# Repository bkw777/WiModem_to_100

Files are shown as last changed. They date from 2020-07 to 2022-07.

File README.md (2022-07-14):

# WiModem232 to "Model T" portable computers

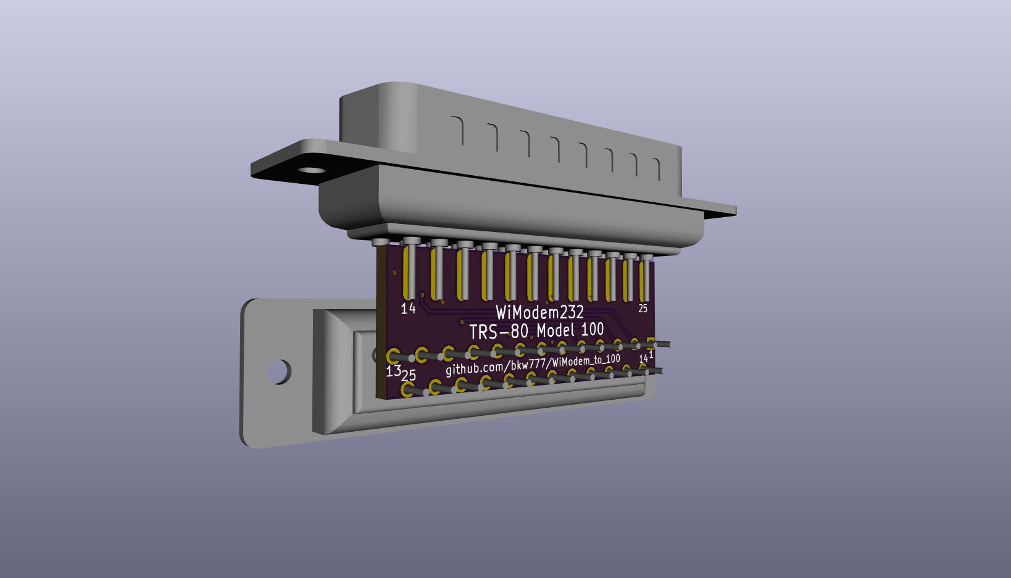
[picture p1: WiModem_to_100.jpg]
  
More pictures: <https://photos.app.goo.gl/hjoC3vnfZxWbFPRW6>



[BOM from DigiKey](https://www.digikey.com/short/z9nm2v)

RS-232 male-male gender-changer for connecting a [WiModem232](https://www.cbmstuff.com/proddetail.php?prod=WiModem232OLED) to a TRS-80 Model 100, or any of the similar machines which has a female DB25 RS-232 DTE connector.

It does 3 things:
- Gender-changer. Both the WiModem232 and Model 100 and clones have female connectors. So a gender-changer or male-male cable is needed to connect them.
- Faces the WiModem232's status led and oled display towards the user. A standard mini gender-changer flips the WiModem232 over so it faces down.
- Holds the Wimodem232 vertical instead of horizontal. This just takes up less desk space and makes it less likely to knock the WiModem232 off of the serial port, and makes it a little easier to read the display from a normal position.

Wired straight-through, not null-modem. The WiModem232, like any other modem or peripheral, is wired as a DCE device, and the Model 100, like any other computer or host, is wired as a DTE device, and so to connect the two, you use a straight-through connection. The RS-232 pins; 1-8, 20, & 22, are connected 1:1 from one connector to the other.  
Pin 1 is also the ground plane / copper pour on both sides of the board.

# Compatibility  
This is for attaching the WiModem232 to any of these machines  
- TRS-80/Tandy Model 100, 200, & 600  
- NEC PC-8201, PC-8201a, & PC-8300  
- Kyocera/Kyotronic KC-85

But notably, NOT these  
- Tandy Model 102  
- Olivetti M10

On Tandy 102 & Olivetti M10 machines, the DB25 connector is upside down, and so this adapter would point the WiModem232 down into the table.

For Tandy 102 & Olivetti M10, you can use an ordinary [25-pin mini gender-changer](https://duckduckgo.com/?q=db25+mini+gender+changer+male), and the WiModem232 will point straight out from the back of the machine instead of standing vertical, and with the LED and OLED screen facing up.

This PCB is designed to use [db25 connectors with through-hole legs](https://www.digikey.com/short/z9nm2v), not solder cups.  

<!--
# Power from BCR port  
<img src="https://github.com/bkw777/BCR_Breakout/blob/master/BCR_USB_PWR.jpg" width=300>  
You can power the WiModem232 from the computer with this <a href="https://github.com/bkw777/BCR_Breakout">BCR-USB power adapter</a> and a usb cable.  

(Not Kyotronic KC-85 or TANDY 600, they do not have a BCR port)

## USB Cables
|Computer Model|Computer End|WiModem232 End|Length|USB Cables|
|---|---|---|---|---|
| TRS-80&nbsp;Model&nbsp;100 | ![](USB_A_100_200.png)<br>![](USB_A_NEC.png) | ![](USB_Mini_ALL.png) | 20cm | <https://amazon.com/dp/B00NIGPK62/><hr><https://www.aliexpress.com/item/32313051153.html><hr><https://www.usbfirewire.com/parts/rr-2mbr01-12gl.html#RR-2MBR01-06GL> |
| TANDY&nbsp;102 | ![](USB_A_102_M10.png)<br>![](USB_A_100_200.png) | ![](USB_Mini_ALL.png) | 40cm | <https://amazon.com/dp/B07WFZHS9D/><hr><https://www.aliexpress.com/item/32312742378.html><hr><https://www.usbfirewire.com/parts/rr-2mbr01-12gl.html#RR-2MBR01-18GL> |
| TANDY&nbsp;200 | ![](USB_A_100_200.png)<br>![](USB_A_NEC.png) | ![](USB_Mini_ALL.png) | 30cm | <https://amazon.com/dp/B07WFZHS9D/><hr><https://www.aliexpress.com/item/4000323097708.html><br>&nbsp;Color: Right<br>&nbsp;Length: 0.5M<hr><https://www.usbfirewire.com/parts/rr-2mbr01-12gl.html#RR-2MBR01-12GL> |
| NEC&nbsp;PC-8201<br>NEC&nbsp;PC-8201a<br>NEC&nbsp;PC-8300 | ![](USB_A_NEC.png) | ![](USB_Mini_ALL.png) | 20cm | <https://www.amazon.com/dp/B07P68QFSH/><hr><https://amazon.com/dp/B01CXT43N0/><hr><https://www.aliexpress.com/item/32404719272.html><br>&nbsp;Color: 4<br>&nbsp;USB-A-Left USB-Mini-Right<hr><https://www.usbfirewire.com/parts/rr-ar4tmbr1-xxg.html#RR-AR4TMBR1-05GL> |
| Olivetti&nbsp;M10 | ![](USB_A_102_M10.png) | ![](USB_Mini_ALL.png) | 30cm | <https://amazon.com/dp/B07P76SHHM/><hr><https://www.aliexpress.com/item/32404719272.html><br>&nbsp;Color: 3<br>&nbsp;USB-A-Right USB-Mini-Right<hr><https://www.usbfirewire.com/parts/rr-ar4mbr1-xxg.html#RR-AR4MBR1-12GL> |
-->

# Case
This is just the standard case from the CBMSTUFF web site, not a new design to include this adapter.  
<https://www.sculpteo.com/en/print/wimodem232_oled_bottom/29Vc6DYz>

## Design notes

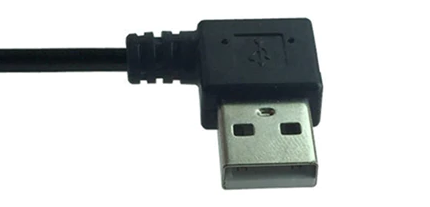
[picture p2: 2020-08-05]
USB_A_102_M10.png

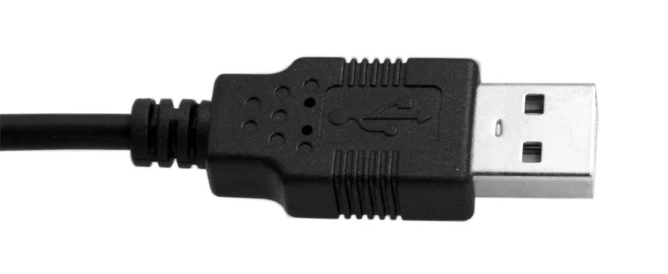
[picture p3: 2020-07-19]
USB_A_100_200.png

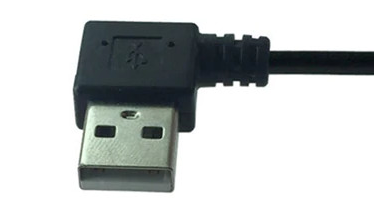
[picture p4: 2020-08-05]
USB_A_NEC.png

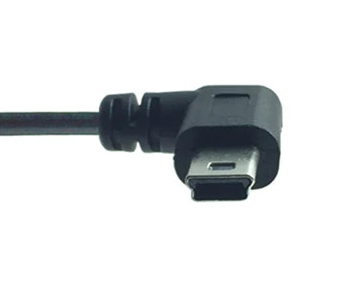
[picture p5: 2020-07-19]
USB_Mini_ALL.png

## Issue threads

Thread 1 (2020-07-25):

Vertical WiModem probably not Tandy 200 compatible

hackerb9, 2020-07-25:
The README mentions that your slick design for attaching a WiModem vertically is compatible with the Tandy 200. However, I would think that the lid/screen would bonk into the WiModem. No?

bkw777, 2020-07-25:
I think you may be right. I'll have to check when I get home. You can flip the adapter around and that makes the wimodem stand a little further away from the computer instead of right against it. That might be just enough. Otherwise, maybe the directions for 200 should just be the same as for 102. IE just use a regular mini gender-changer, because if you can't see the wimodem behind the screen anyway, then it doesn't matter much if the led is facing up or down.

I'll update the readme when I get a chance to look at my 200.

bkw777, 2020-07-29:
I have checked it out with my 200 now.
It's mostly ok.

If you install the adapter one way with the wimodem closest to the 200, then the screen still does not hit the wimodem when the screen is at the detent angle, but does hit the wimodem when you open the screen past the detent to the end of it's travel, but even then, not bad enough to hurt. It pushes the top of the wimodem back about 1/4". Not enough to even bend the pins in the connectors. Although definitely the connections are no longer straight.

If you install the adapter the other way, the wimodem is both further away from the back of the 200, and lower too, and then the screen just barely touches the wimodem when you open the screen as far as possible, even with a right-angle usb cord plugged in.

A straight usb plug in the wimodem makes both of those worse.

However, like I imagined before, since the wimodem is behind the screen, there isn't much reason to use this adapter anyway on a 200, since you can't see the wimodem anyway. You might as well just use a regular mini gender-changer. Or, if you want to see the led or the oled, then you'll need a 25-pin cable anyway to relocate the wimodem out from behind the screen. In either case you still don't need this adapter to provide the gender-change and don't need the 90-degree.

But, just for completeness, the orientation of the "D" shape of the db25 connector on the 200 is correct for this adapter, so the wimodem stands up away from the table not pointing down into it (like what would happen on a 102)
and you might possibly still want to use this adapter just for safety and to reduce the desktop footprint. The wimodem laying straight out from the back of the 200 takes up more desktop and is at risk of being stressed.

hackerb9, 2020-07-30:
Thanks for trying it out.  I think you are correct that a 200 user would want to use the adapter in the second configuration just to keep the desk footprint smaller. The risk of stress is significant and would be moreso for people who use their 200s on their laps.

Closed 2020-07-30.

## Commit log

2020-07-08 ground plane
    [WiModem_to_100.kicad_pcb]
2020-07-08 tiny adjustments to routing and ground plane connections
    [WiModem_to_100.kicad_pcb]
2020-07-15 widen through-holes, improve readme
    [WiModem_to_100.kicad_pcb]
2020-07-16 edge connector too close to normal connector
    [WiModem_to_100.kicad_pcb]
2020-07-19 illustrate usb cables
2020-07-22 larger drills
    [WiModem_to_100.kicad_pcb]
2020-08-05 update usb cables
2020-08-16 notes in .sch, remove .stl, change img from png to jpg
    [WiModem_to_100.sch]
